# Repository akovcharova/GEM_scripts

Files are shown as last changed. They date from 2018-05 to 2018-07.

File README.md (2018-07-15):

# GEM_scripts

Follow these steps for creating a GE2/1 readout board. 

## Notes

There are a set of holes on each board for mounting and fixation which are usually added by Bertrand (CERN). The inputs for this are not yet described in this guide. Coming soon...

## Step 1. Generating DXF with strip gaps and traces

Generating this DXF is done by the `make_ge21_rob.py` and requires as input a DXF of the outline of the module, the chimney boundary, and the active area. This info is contained in two mechanical drawings for each of the modules, which are produced by Stephane Brachet and stored in the directory `in`. 

With these two input files in hand, the procedure is as follows:

1. The variables `block_label` and `chimney_label` contain the names of the reference blocks in the AutoCAD drawing representing the board outline and chimney. These have already been entered in the script for all the modules, but you should double check them. They can be read off from the input DXFs by double-clicking on the "reference block" representing the module in the drawing and reading its name. 

2. Enter the coordinates of the top two corners of the active area in the `segm_def` list (you only need the top two corners since the board is symmetric around Y=0). These two points can be read off by running `check_dxf.py` on the input DXF `GE21_M#_outline.dxf`, e.g. for module 2: `./check_dxf.py -m 2`. The script will transfer the outline to a new file `out/GE21_M#.dxf`. You can open this and look at the approximate coordinates of the two corners in order to know which numbers to take from the print out.

3. Finally, fill the list `conn_list` with the coordinates and rotation angle for each of the 12 connectors. You can start by just copying the coordinates from a similar module (e.g. take coordinates from M1 as initial guess for M5). Run the script: `./make_ge21_rob.py -m 2`. Considerations for placement of connectors include:
    * connectors must be fully contained within the aluminum bars denoted by dotted lines
    * `> 5 mm` clearance from any other object as well as from the aluminum bars
    * For M1 and M5, `> 20 mm` clearance for connectors 10 and 11 from the aluminum bar for routing of low voltage; for other modules the clearance of `> 20 mm` is needed also for connectors 4 and 5 since the wires will be coming in from the previous module
    * `> 35 mm` clearance for connector 6 and > 20 mm for connector 7 from the aluminum bar for routing fibers
    * `> 23 mm` wide path for routing signals from each GEB/VFAT connector to one of the two GEB/OH connectors, this is not always possible, consult GEB designers if in doubt (for M5, similar choices to M1 should be ok)
    * `> 55 mm` for a master-slave cable (note that cable goes in opposite direction for Master vs Slave modules)

4. Run `make_ge21_rob.py` to obtain the DXF and examine it in AutoCAD. Debug mode shows the different sets of strips in different colors and hides the routing to make it easier to see things when initially deciding on connector placement. 

5. When happy with the positions. Run above with `debug = False` to show the routing. Carefully check if it all looks reasonable and make sure there is no traces that are too close or overlapping; examine also if any traces pass too close to the vias. Clearances of > 0.2 mm should be sufficient. 

## Step 2. Import DXF into Altium

For installing a script project see here:

1. Open Altium and create new empty PCB project

2. Create a new PCB document 

3. Press `Q` to switch the units to mm

4. Import DXF only:
    * `File > Import > DXF`
    * Select the DXF file 
    * Fill in the pop-up titled `Import from AutoCAD` as follows:

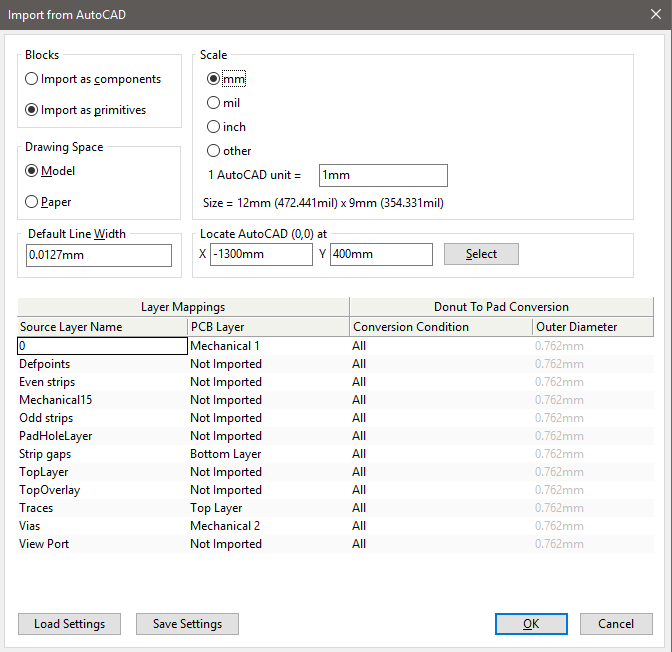
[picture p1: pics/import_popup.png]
    

    * The AutoCAD origin should be placed such that the board itself is not too far from the Altium origin and also completely contained in positive Y, see GE2/1 M1 here:
    * For simplicity, the traces are not assigned to nets. This means that Altium's default design rules will find violations with all the traces. I disable them as follows:

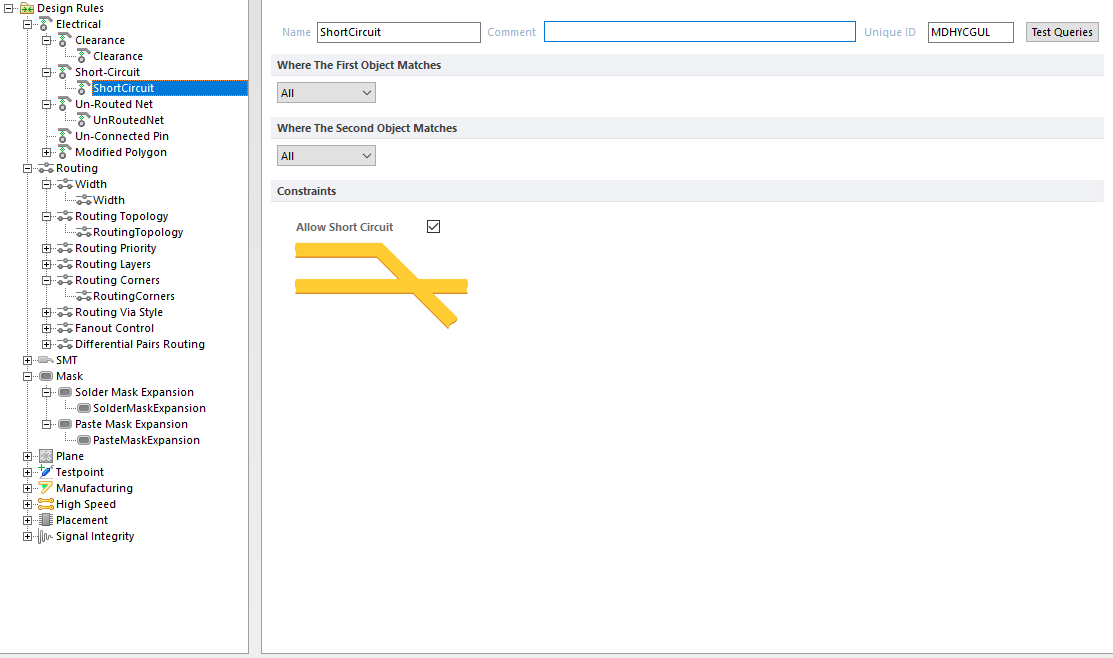
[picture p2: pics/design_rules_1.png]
    
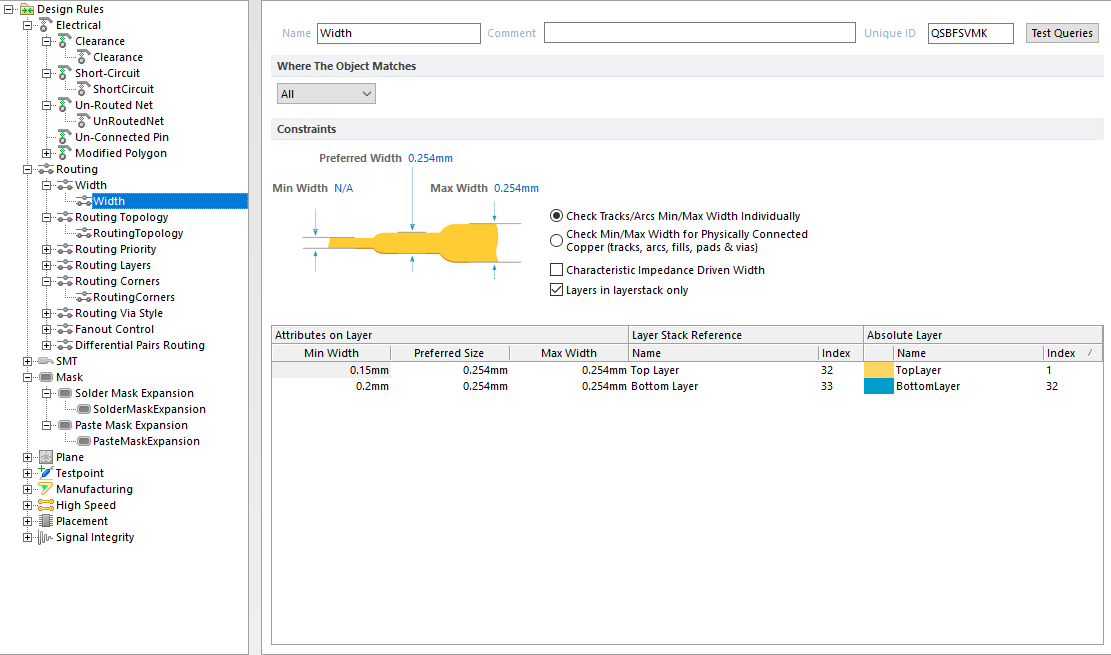
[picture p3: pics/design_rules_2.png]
    
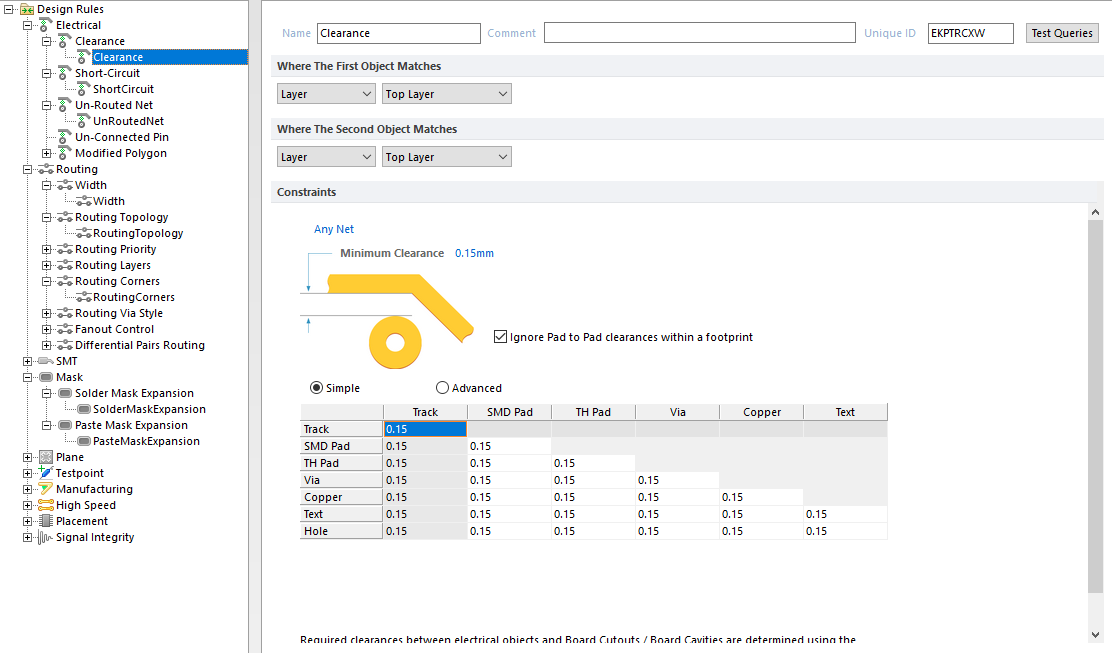
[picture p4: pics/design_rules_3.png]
    

    * As a result Altium will not be able to detect all possible violations so it's worth checking by eye if any traces look too close. It could be a future improvement to implement the net assignment to make Altium's checks more reliable.

5. Define the board
    * Select the outline as shown on the left, go to `Design > Board Shape > Define from selected objects` - a warning about using external edges may pop, press `Yes`. The result should look like the right pic

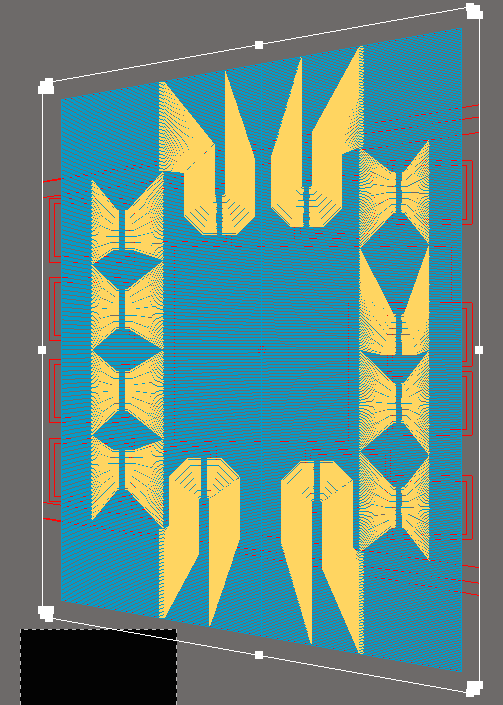
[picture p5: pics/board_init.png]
    
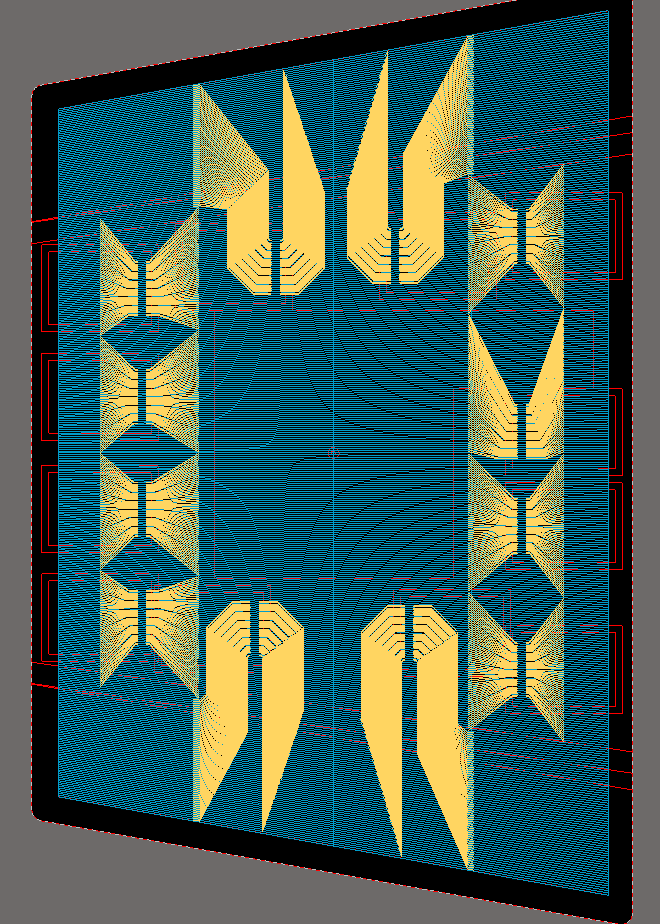
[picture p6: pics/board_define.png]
    

    * Save PCB before continuing.

6. Place 12 connectors next to the board, the exact position is not important, we will move them next. Save PCB (Altium crashes a lot...)

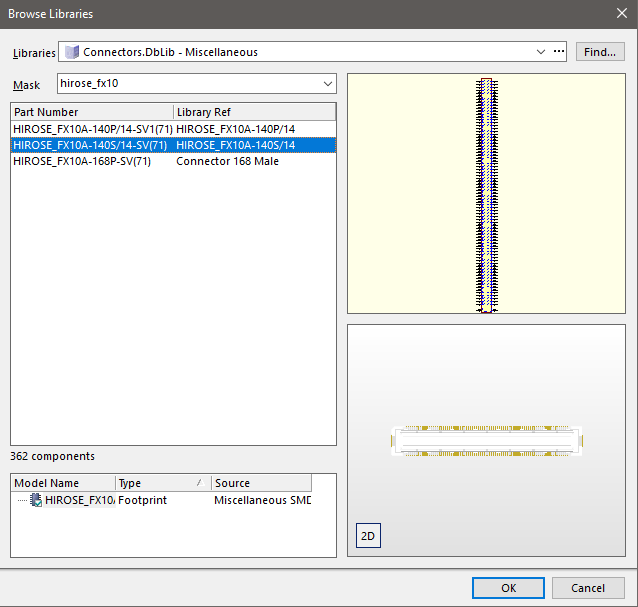
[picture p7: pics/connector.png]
    
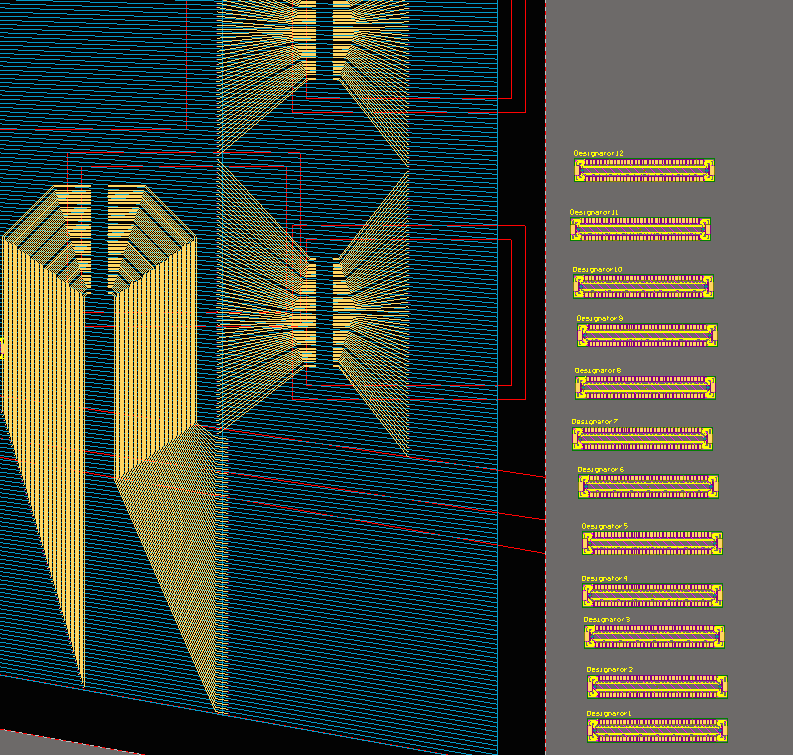
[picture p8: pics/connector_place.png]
    

7. Only the first time making a board, "install" the script in Altium
    * Create a scripting project and add the file `altium/place_comps_ge21_rob.js` to it
    * In order to use this with any board, we install it as a global project: go to `DXP > Preferences`, select `Scripting System > Global Projects`, click on `Install` and select the scripting project you created

8. Placing the vias and moving components to the proper positions
    * open the script `altium/place_comps_ge21_rob.js` for editing
    * copy the functions `CreateViaArray_GE21...` and `CreateConnectorArray_GE21...` written by the python script `make_ge21_rob.py` in Step 1; these can be found in `via_coord/`*board_name*`_coord.js` (I've tried to make this less clunky, but could not get Altium to open the additional file by itself so far)
    * change the variable `board_name` to the appropriate label 
    * add the new case to the switch, the values for `offset_x` and `offset_y` should be the same you used when placing the AutoCAD origin when importing the DXF, and the functions names should be the ones you just pasted, e.g.:
    ```
     else if (board_name=="GE21_M4") {
        offset_x = -2650;
        offset_y = 650;
        CreateConnectorArray_GE21_M4();
        CreateViaArray_GE21_M4();
    }
    ```
    * run the script by going to `DXP > Run Script` in the pop-up select the function `Main` under `place_comps_ge21_rob.js` and click `OK`
    * Wait... depending on how much RAM you have could be a minute, or a few, until Altium is fully responsive again

9. Export manufacturing outputs
    * Go to `File > Fabrication Outputs > Gerber Files`, choose the units in `mm`, and from the layers select top, bottom and mechanical 1
    * Go to `File > Fabrication Outputs > NC Drill Files`, choose the units in `mm`

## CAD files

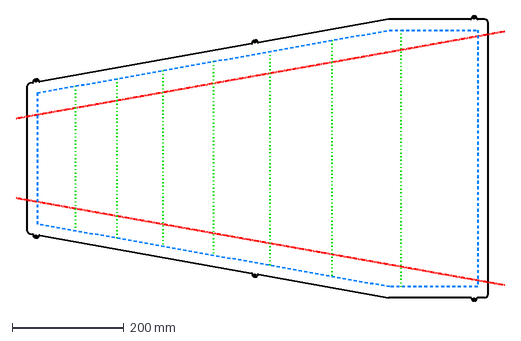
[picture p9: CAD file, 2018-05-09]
out/ME0.dxf
875.3 x 509.4 mm

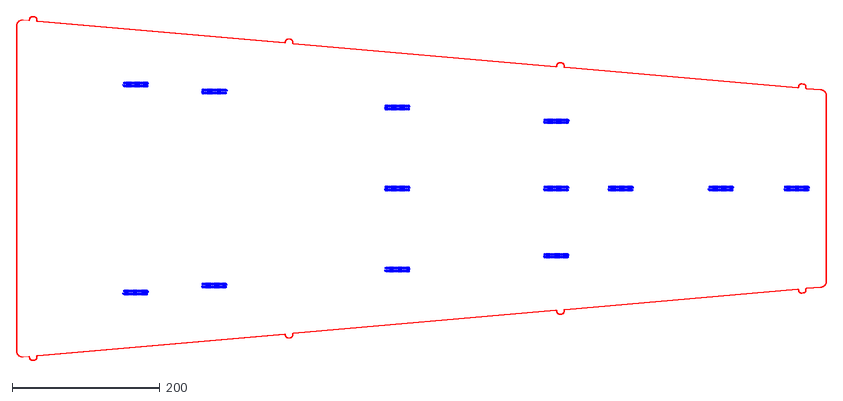
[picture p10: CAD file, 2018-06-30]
in/GE11_skeleton.dxf
1096.3 x 466.2

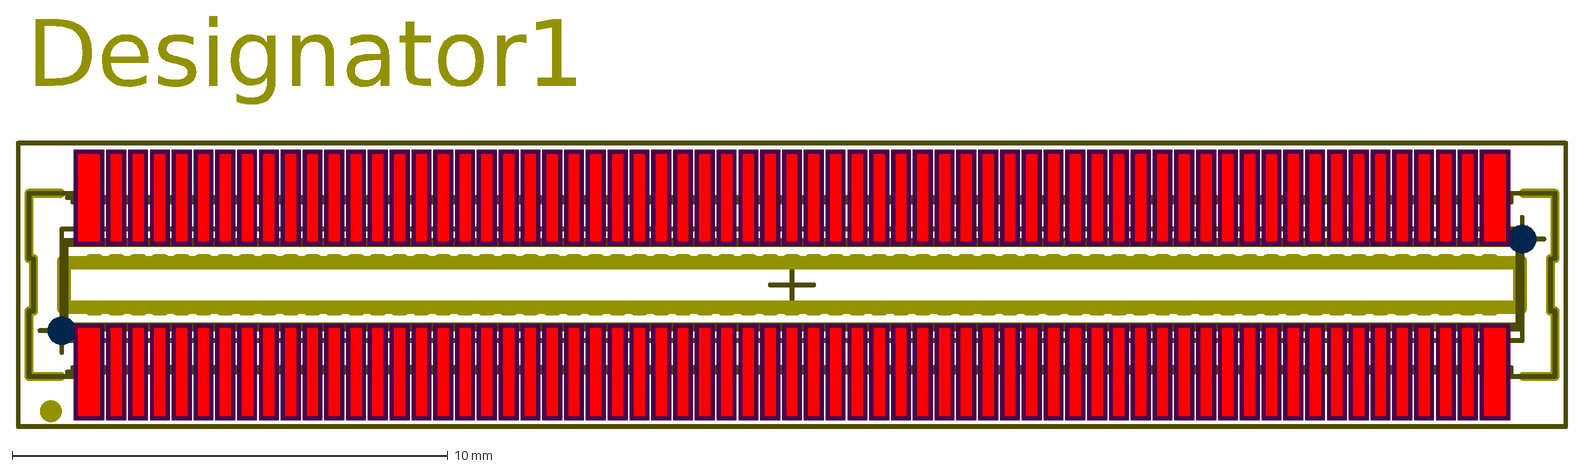
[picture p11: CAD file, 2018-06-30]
in/PANASONIC_all_layers.DXF
Designator1

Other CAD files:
in/GE21_M4_chimney.dxf
in/GE21_M8_chimney.dxf
in/GE21_M2_chimney.dxf
in/GE21_M3_chimney.dxf
in/GE21_M7_chimney.dxf
in/GE21_M5_chimney.dxf
in/GE21_M1_chimney.dxf
in/GE21_M6_chimney.dxf
in/GE21_M7_outline.dxf
in/GE21_M2_outline.dxf
in/GE21_M3_outline.dxf
in/GE21_M6_outline.dxf
in/GE21_M8_outline.dxf
in/GE21_M4_outline.dxf
in/ME0_outline.dxf
in/GE21_M1_outline.dxf
in/GE21_M5_outline.dxf
in/HIROSE_FX10A_140S_14_SV.dxf

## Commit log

2018-01-16 Added script to make schematic (still need to adjust sheet). Slow...
2018-03-16 Adjust via rows to accomodate opto-hybrid and connectors, print via centers
2018-03-28 Scripts to place vias and move connectors to desired position in Altium
2018-03-31 Adapted scripts to GE21 M4, added connector spines and added script to mirror routing.
2018-04-08 Updates to connector position, rotation and grounding after meeting with Bertrand.
2018-05-09 Added script used to study connector orientations and OH placement and dimensions for 18-04-26 slides
2018-05-09 Organize files
    [GE21_M1.dxf, GE21_M1_chimney.dxf, GE21_M1_outline.dxf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]
2018-06-18 GE11-sized prototype preparation.
    [GE21_M1.dxf]
2018-06-30 Prepared scripts for generating GE21 layouts. Used for GE21_M1_v1.
    [GE11_skeleton.dxf, GE21_M1_chimney.dxf, GE21_M2_chimney.dxf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]
2018-07-15 Set positions for GE21 M2-M4 and update chimney drawings
    [GE21_M1_chimney.dxf, GE21_M2_chimney.dxf, GE21_M3_chimney.dxf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]
2018-07-15 Tweaks to routing and update to altium script to adjust for multiple boards
2018-07-25 Added connector and via positions for M5 ROB
